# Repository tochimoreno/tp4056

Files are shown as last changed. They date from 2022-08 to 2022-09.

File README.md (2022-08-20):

# Batery charger with TP4056, protection and power path
forked from ...

Tomo el proyecto original como base para realizar uno nuevo que incluya un power path para mejor funcionamiento del cargador.

* Clean up and redraw the schematic
* Add power path
* Remove KiCad v5 files
* Add 3V3 LDO regulator
* Add divisor for measurment Bat voltage

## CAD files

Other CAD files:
tp4056_kicad6_base/tp4056.dxf

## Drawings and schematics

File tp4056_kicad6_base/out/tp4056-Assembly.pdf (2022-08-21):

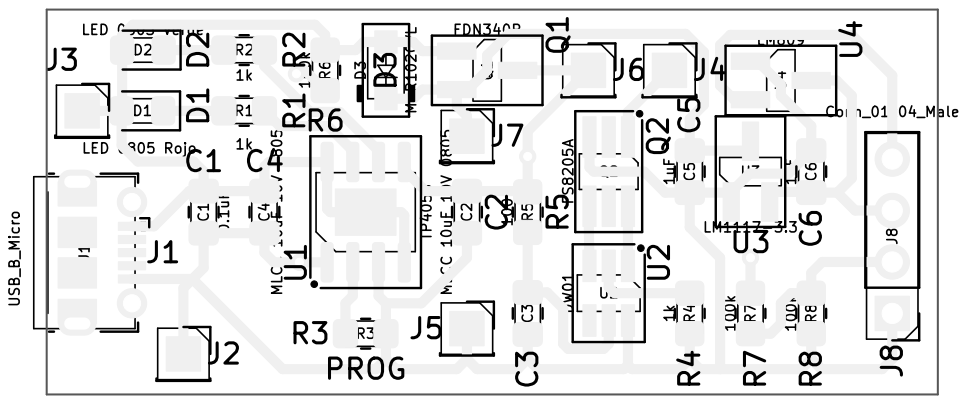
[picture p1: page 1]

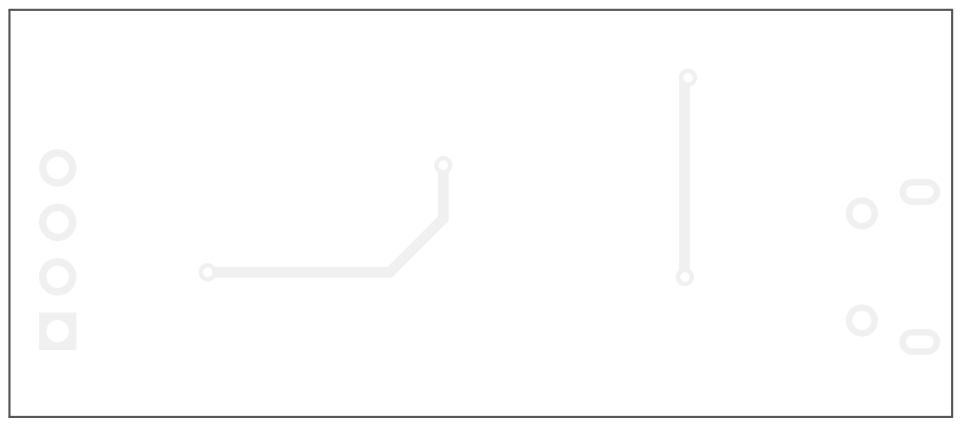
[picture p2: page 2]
D Date: KiCad E.D.A. kicad 6.0.7-f9a2dced07~116~ubuntu22.04.1 Size: A4; Rev:; Id: 1/1 Title:; File: tp4056.kicad_pcb; Sheet: Assembly

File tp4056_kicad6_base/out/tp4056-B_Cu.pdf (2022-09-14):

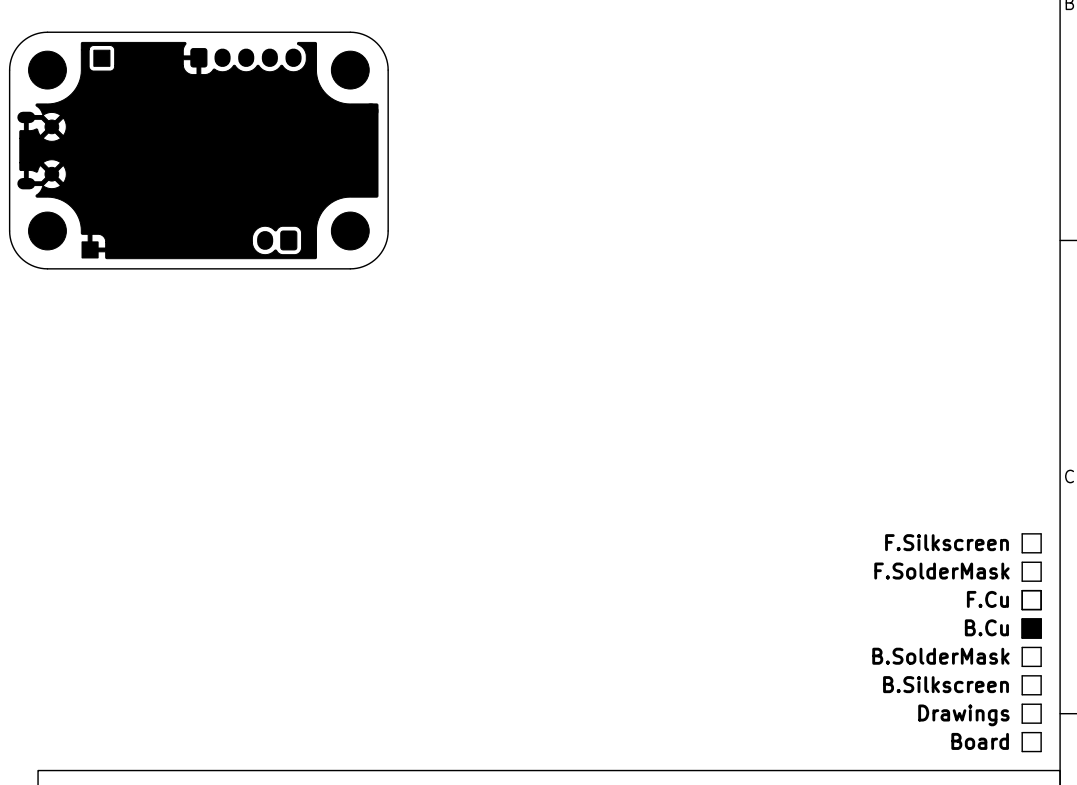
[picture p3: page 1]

F.SolderMask F.Silkscreen B.SolderMask F.Cu B.Cu B.Silkscreen Drawings

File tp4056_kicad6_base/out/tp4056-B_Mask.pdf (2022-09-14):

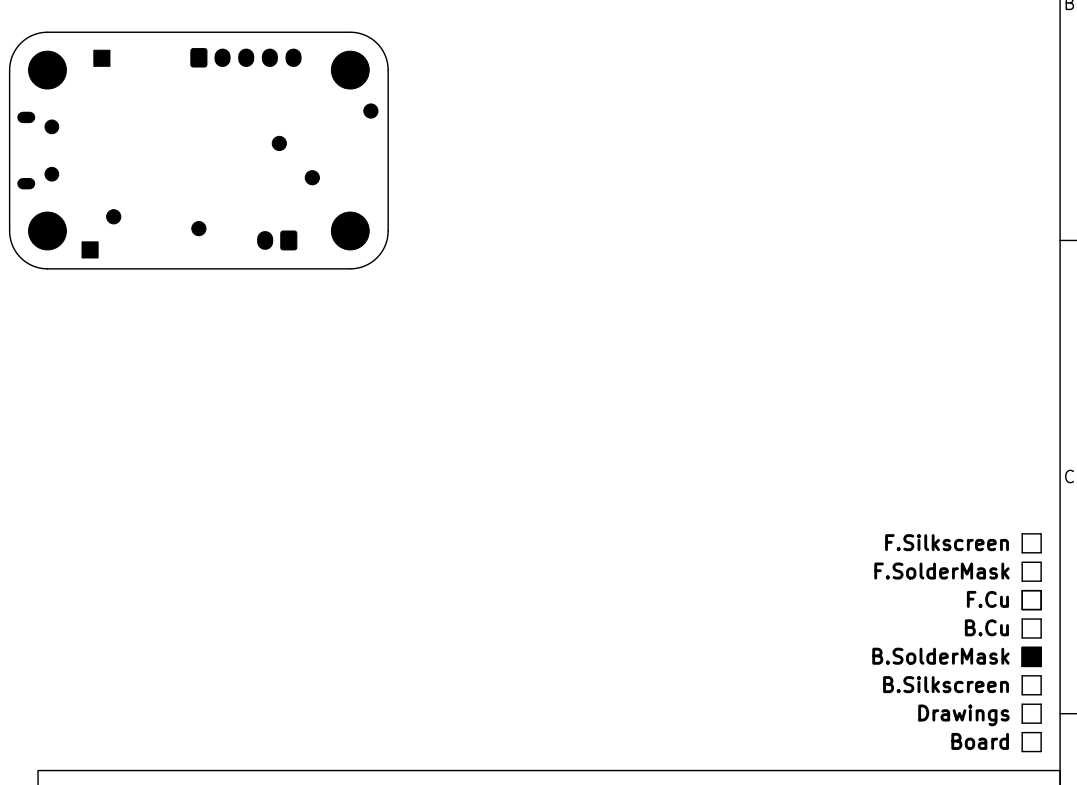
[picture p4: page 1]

F.SolderMask F.Silkscreen B.SolderMask F.Cu B.Cu B.Silkscreen Drawings

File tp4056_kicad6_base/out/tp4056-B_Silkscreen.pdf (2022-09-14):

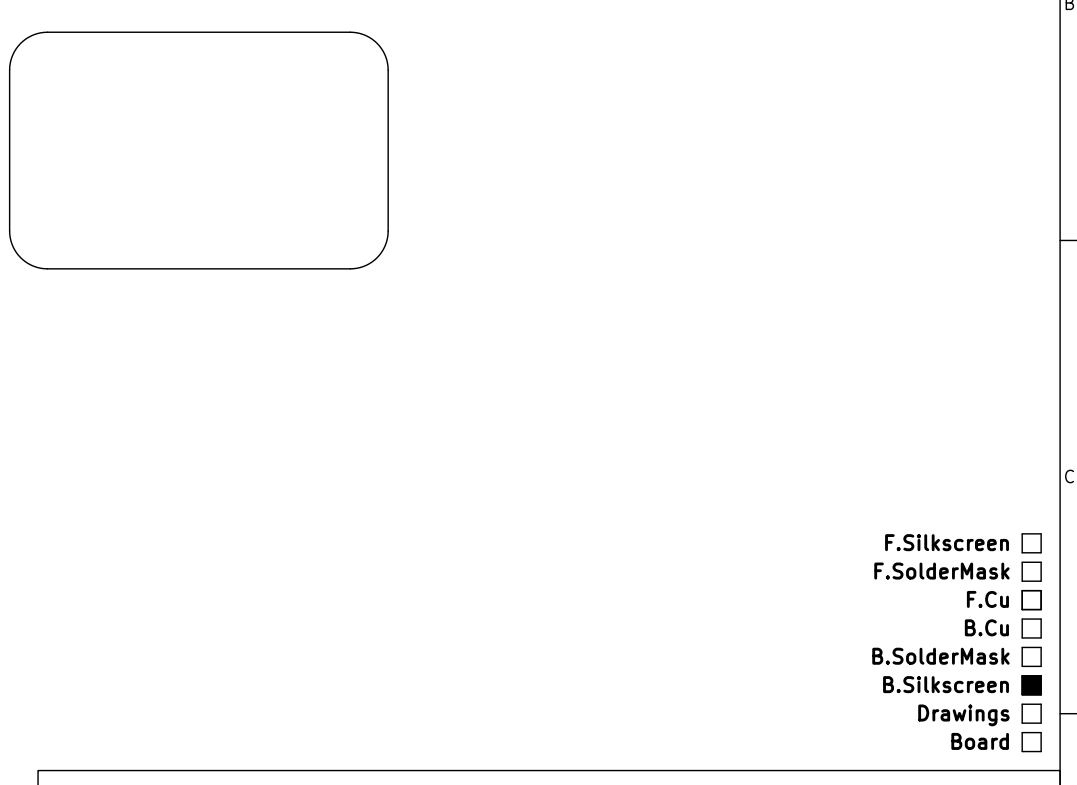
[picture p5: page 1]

F.SolderMask F.Silkscreen B.SolderMask F.Cu B.Cu B.Silkscreen Drawings

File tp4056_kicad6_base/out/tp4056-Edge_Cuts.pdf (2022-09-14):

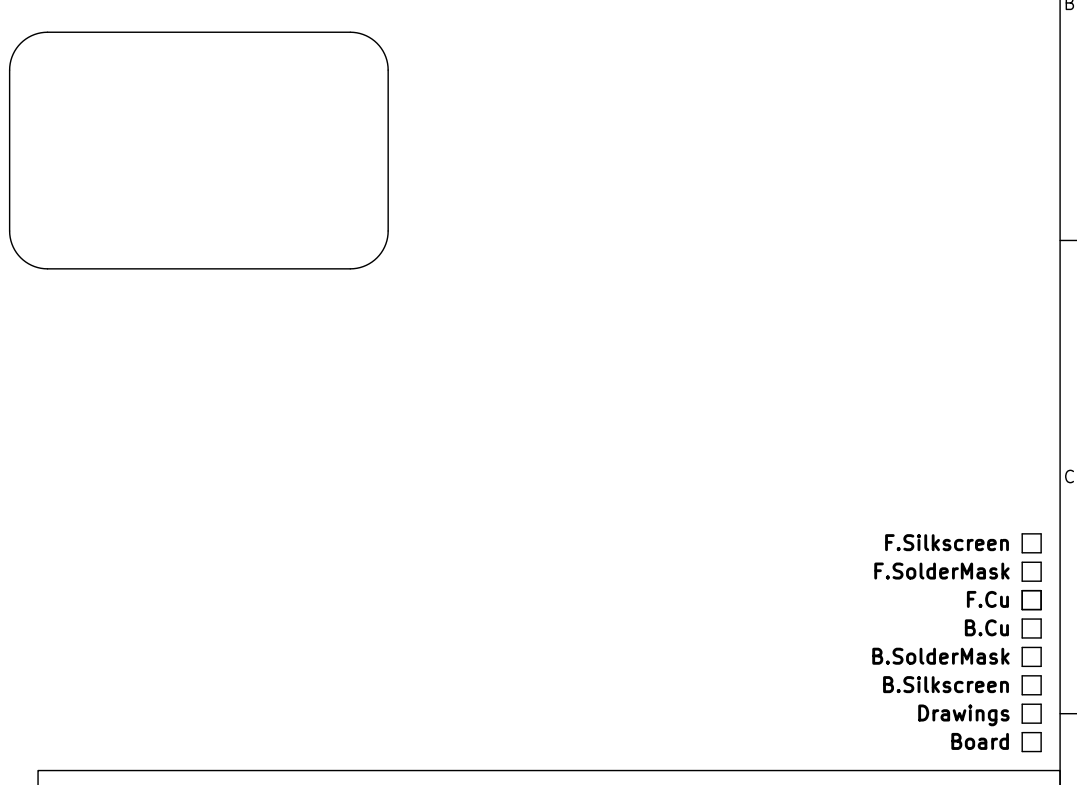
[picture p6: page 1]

F.SolderMask F.Silkscreen B.SolderMask F.Cu B.Cu B.Silkscreen Drawings

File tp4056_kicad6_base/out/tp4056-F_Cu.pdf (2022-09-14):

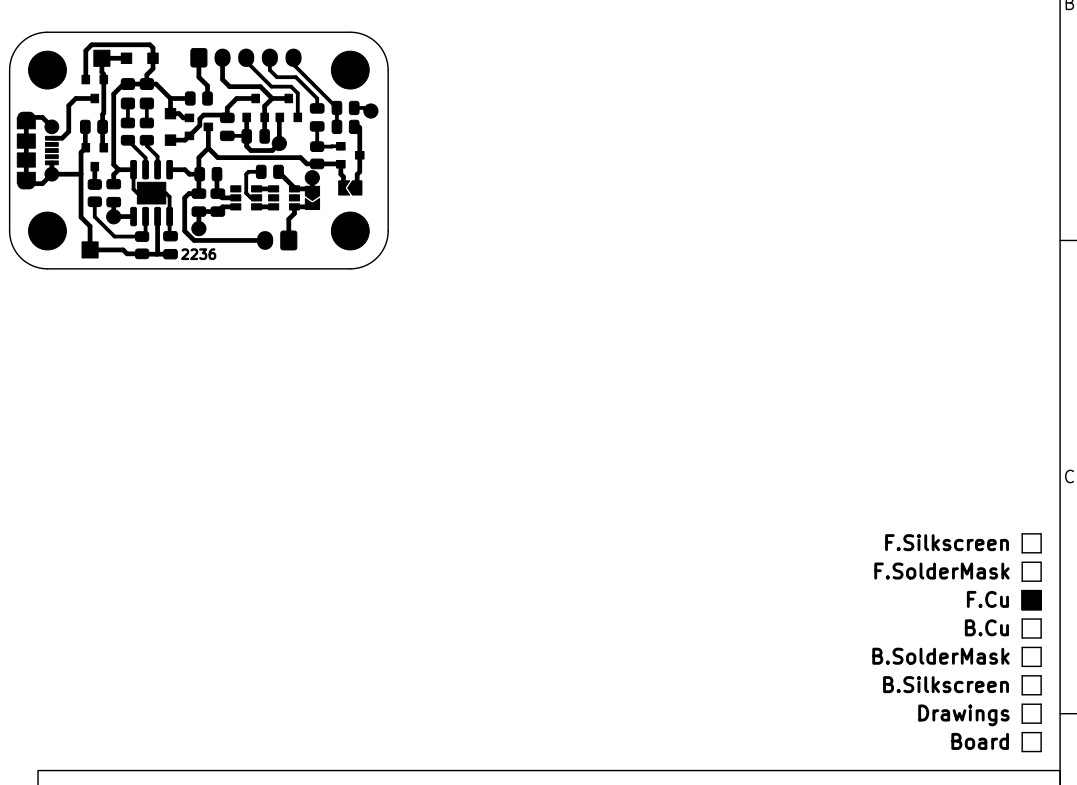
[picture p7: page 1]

F.SolderMask F.Silkscreen B.SolderMask F.Cu B.Cu B.Silkscreen Drawings

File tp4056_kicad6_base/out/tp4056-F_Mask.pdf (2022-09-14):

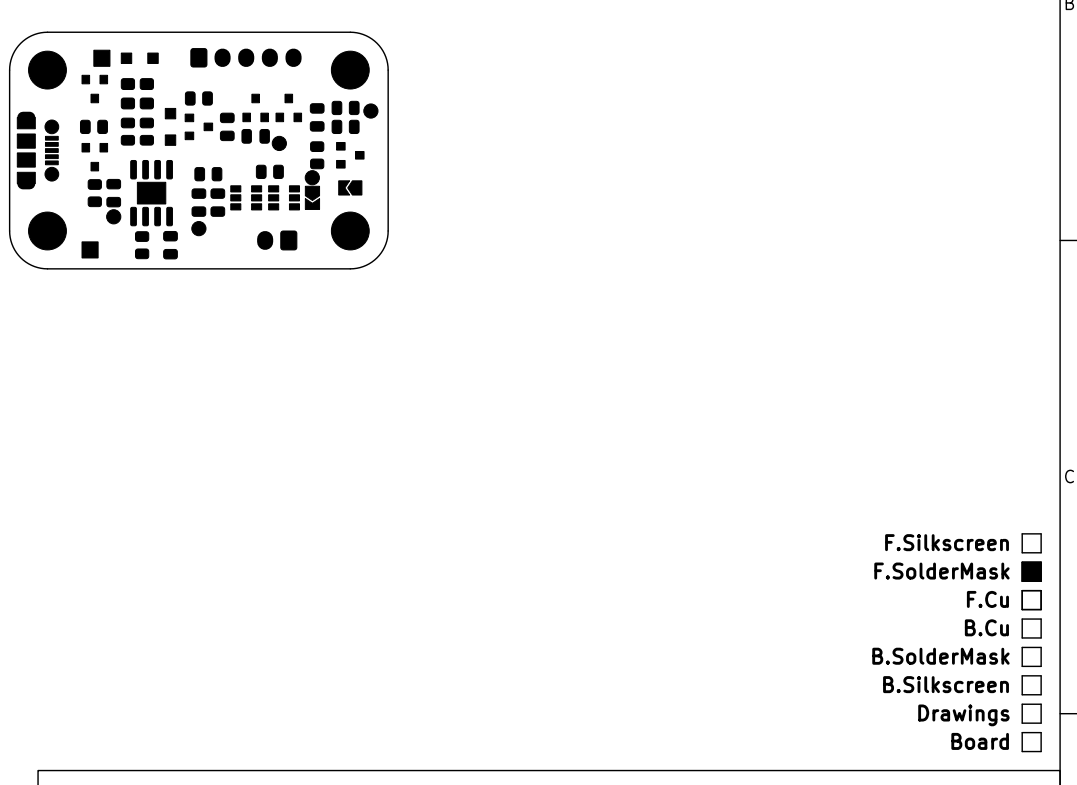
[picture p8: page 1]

F.SolderMask F.Silkscreen B.SolderMask F.Cu B.Cu B.Silkscreen Drawings

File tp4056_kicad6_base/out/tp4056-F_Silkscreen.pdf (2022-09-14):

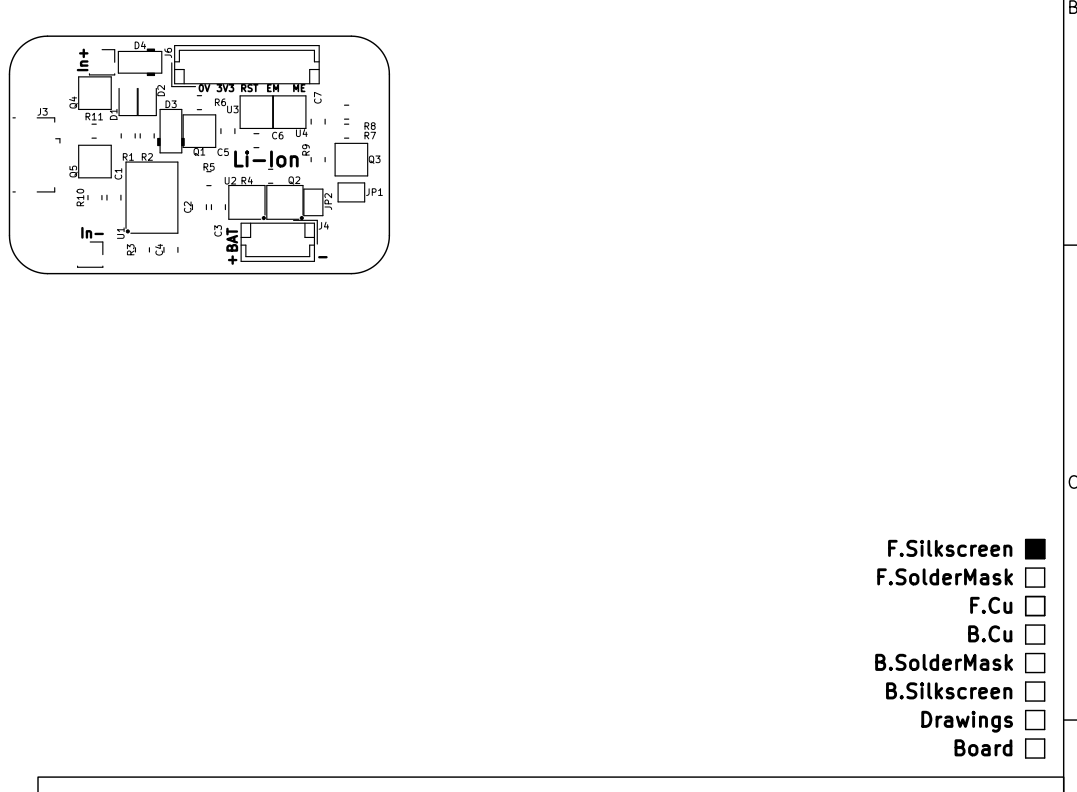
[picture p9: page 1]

0V 3V3 RST EM ME In+

F.SolderMask F.Silkscreen B.SolderMask F.Cu B.Cu B.Silkscreen Drawings

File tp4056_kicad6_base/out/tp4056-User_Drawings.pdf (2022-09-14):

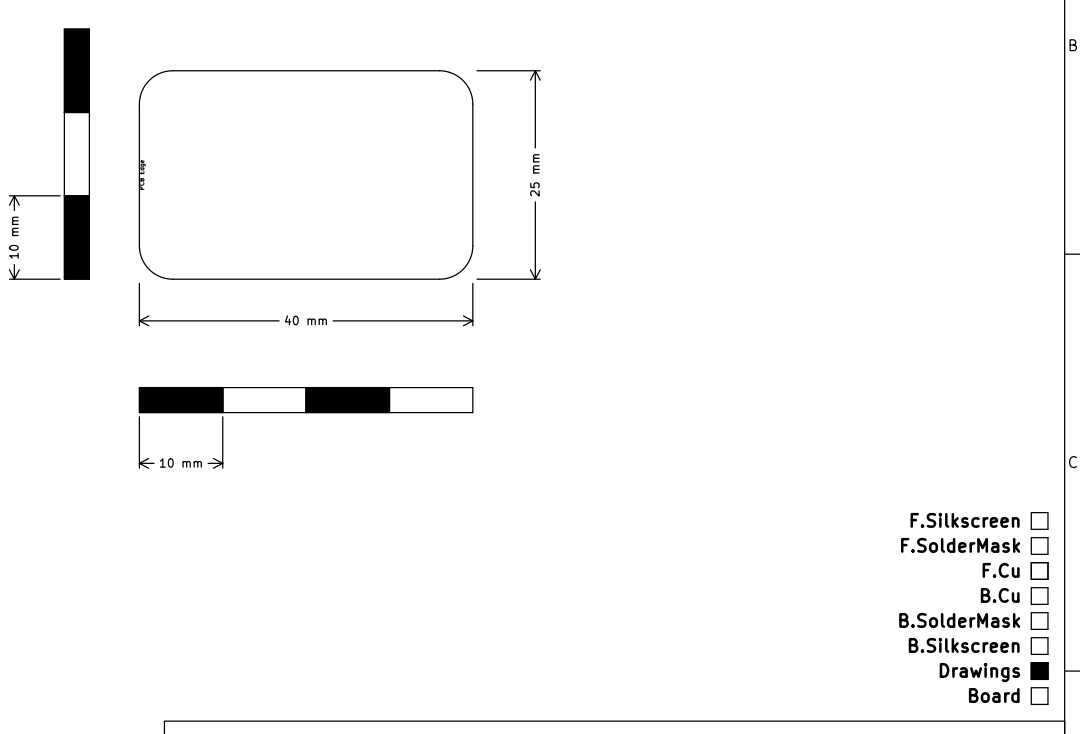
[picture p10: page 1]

F.SolderMask F.Silkscreen B.SolderMask F.Cu B.Cu B.Silkscreen Drawings 25 mm 10 mm

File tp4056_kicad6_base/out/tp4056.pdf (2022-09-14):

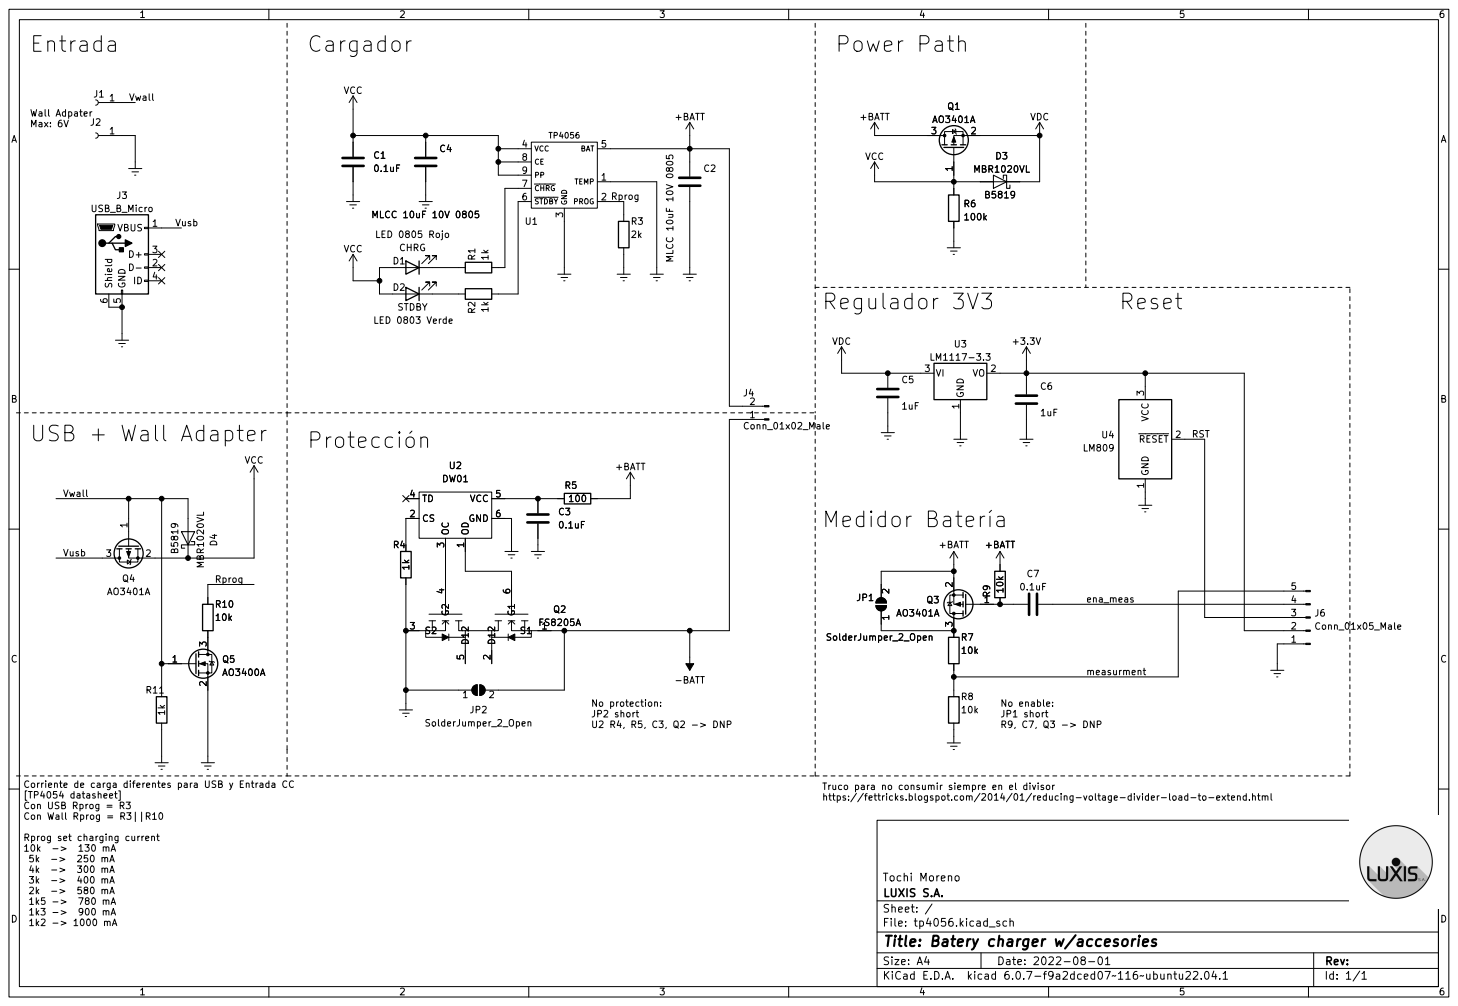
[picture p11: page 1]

3 TD 4 VCC 5 GND 6 U2 DW01 VBUS 1 D- 2 D+ 3

No enable: JP1 short R9, C7, Q3 -> DNP USB + Wall Adapter

No protection: JP2 short U2 R4, R5, C3, Q2 -> DNP

Corriente de carga diferentes para USB y Entrada CC
[TP4054 datasheet]
Con USB Rprog = R3
Con Wall Rprog = R3||R10

Truco para no consumir siempre en el divisor
https://fettricks.blogspot.com/2014/01/reducing-voltage-divider-load-to-extend.html

Rprog set charging current 10k -> 130 mA

Id: 1/1 Title: Batery charger w/accesories

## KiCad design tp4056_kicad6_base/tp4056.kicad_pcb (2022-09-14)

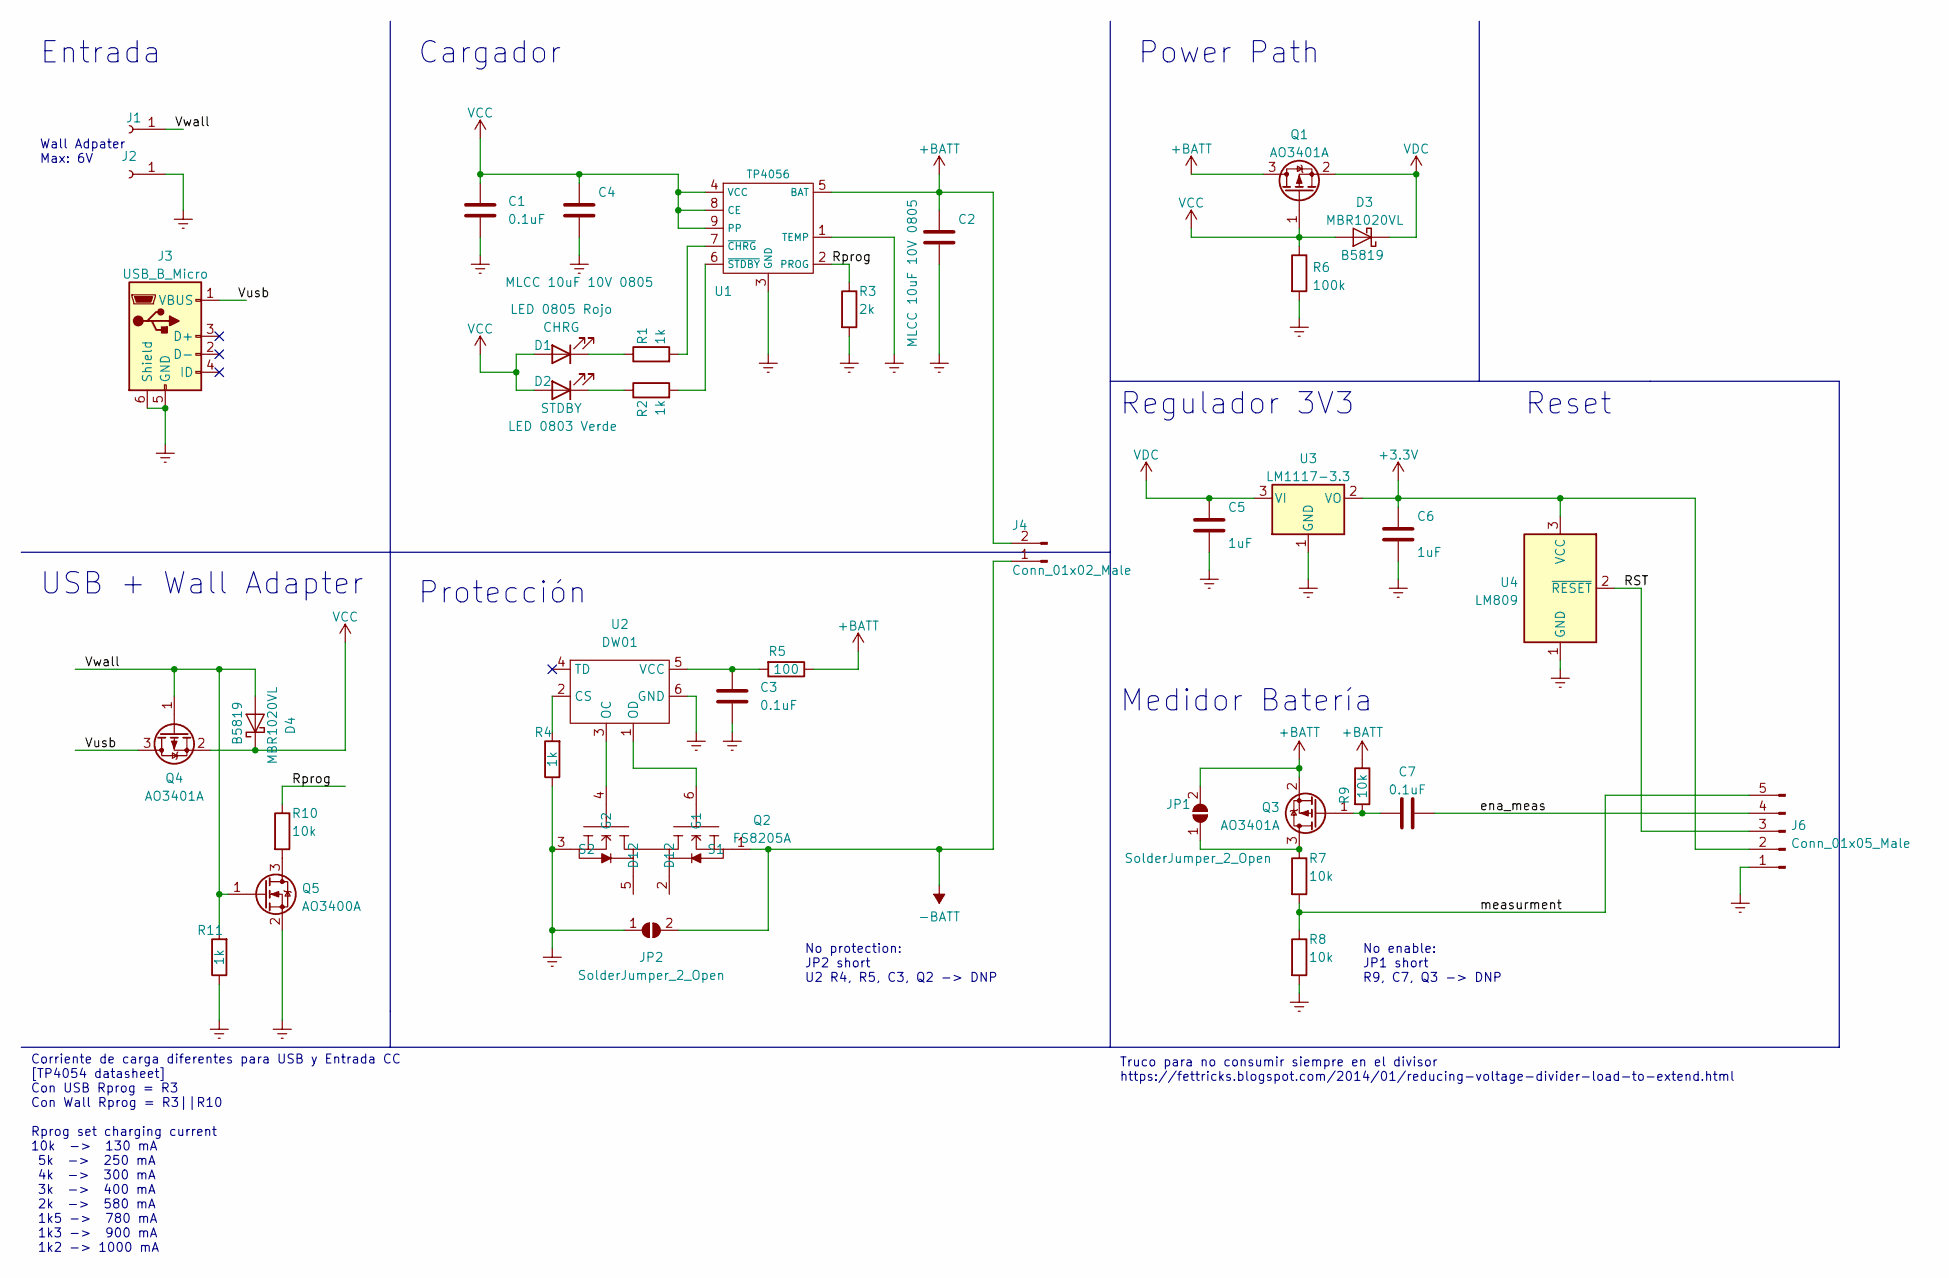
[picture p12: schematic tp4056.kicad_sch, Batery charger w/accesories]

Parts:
C1, C3, C7: 0.1uF; C_0805_2012Metric
C2, C4: MLCC 10uF 10V 0805; C_0805_2012Metric
C5, C6: 1uF; C_0805_2012Metric
D1: LED 0805 Rojo; LED_0805_2012Metric_Pad1.15x1.40mm_HandSolder
D2: LED 0803 Verde; LED_0805_2012Metric_Pad1.15x1.40mm_HandSolder
D3, D4: MBR1020VL; D_SOD-123F
J1, J2: Conn_01x01_Female; PinSocket_1x01_P2.54mm_Vertical
J3: USB_B_Micro; USB_Micro-B_Molex-105017-0001
J4: Conn_01x02_Male; JST_EH_B2B-EH-A_1x02_P2.50mm_Vertical
J6: Conn_01x05_Male; JST_EH_B5B-EH-A_1x05_P2.50mm_Vertical
JP1, JP2: SolderJumper_2_Open; SolderJumper-2_P1.3mm_Open_TrianglePad1.0x1.5mm
Q1, Q3, Q4: AO3401A; SOT-23
Q2: FS8205A; SOT-23-6
Q5: AO3400A; SOT-23
R1, R2, R4, R11: 1k; R_0805_2012Metric
R3: 2k; R_0805_2012Metric
R5: 100; R_0805_2012Metric
R6: 100k; R_0805_2012Metric
R7, R8, R9, R10: 10k; R_0805_2012Metric
U1: TP4056; SOIC-8-1EP_3.9x4.9mm_P1.27mm_EP2.29x3mm
U2: DW01; SOT-23-6
U3: LM1117-3.3; SOT-23
U4: LM809; SOT-23

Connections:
+3.3V: C6.1, J6.2, U3.2 (VO), U4.3 (VCC)
+BATT: C2.1, J4.2, JP1.2 (B), Q1.3 (D), Q3.2 (S), R5.1, R9.1, U1.5 (BAT)
-BATT: J4.1, JP2.2 (B), Q2.1 (S1)
/RST: J6.3, U4.2 (~RESET)
/Rprog: R3.1, R10.1, U1.2 (PROG)
/Vusb: J3.1 (VBUS), Q4.3 (D)
/Vwall: D4.2 (A), J1.1, Q4.1 (G), Q5.1 (G), R11.2
/ena_meas: C7.2, J6.4
/measurment: J6.5, R7.2, R8.1
Earth: C1.2, C2.2, C3.2, C4.2, C5.2, C6.2, J2.1, J3.5 (GND), J3.6 (Shield), J6.1, JP2.1 (A), Q2.3 (S2), Q5.2 (S), R3.2, R4.1, R6.2, R8.2, R11.1, U1.1 (TEMP), U1.3 (GND), U2.6 (GND), U3.1 (GND), U4.1 (GND)
unnamed: C3.1, R5.2, U2.5 (VCC)
unnamed: C7.1, Q3.1 (G), R9.2
unnamed: D1.1 (K), R1.1
unnamed: D2.1 (K), R2.1
unnamed: JP1.1 (A), Q3.3 (D), R7.1
unnamed: Q2.4 (G2), U2.3 (OC)
unnamed: Q2.6 (G1), U2.1 (OD)
unnamed: Q5.3 (D), R10.2
unnamed: R1.2, U1.7 (~CHRG)
unnamed: R2.2, U1.6 (~STDBY)
unnamed: R4.2, U2.2 (CS)
VDC: C5.1, D3.1 (K), Q1.2 (S), U3.3 (VI)

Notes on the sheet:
Power Path
Corriente de carga diferentes para USB y Entrada CC [TP4054 datasheet] Con USB Rprog = R3 Con Wall Rprog = R3||R10 Rprog set charging current 10k -> 130 mA 5k -> 250 mA 4k -> 300 mA 3k -> 400 mA 2k -> 580 mA 1k5 -> 780 mA 1k3 -> 900 mA 1k2 -> 1000 mA
No protection: JP2 short U2 R4, R5, C3, Q2 -> DNP
Medidor Batería
USB + Wall Adapter
Reset
Truco para no consumir siempre en el divisor https://fettricks.blogspot.com/2014/01/reducing-voltage-divider-load-to-extend.html
Cargador
Protección
Entrada
Wall Adpater Max: 6V
No enable: JP1 short R9, C7, Q3 -> DNP
Regulador 3V3

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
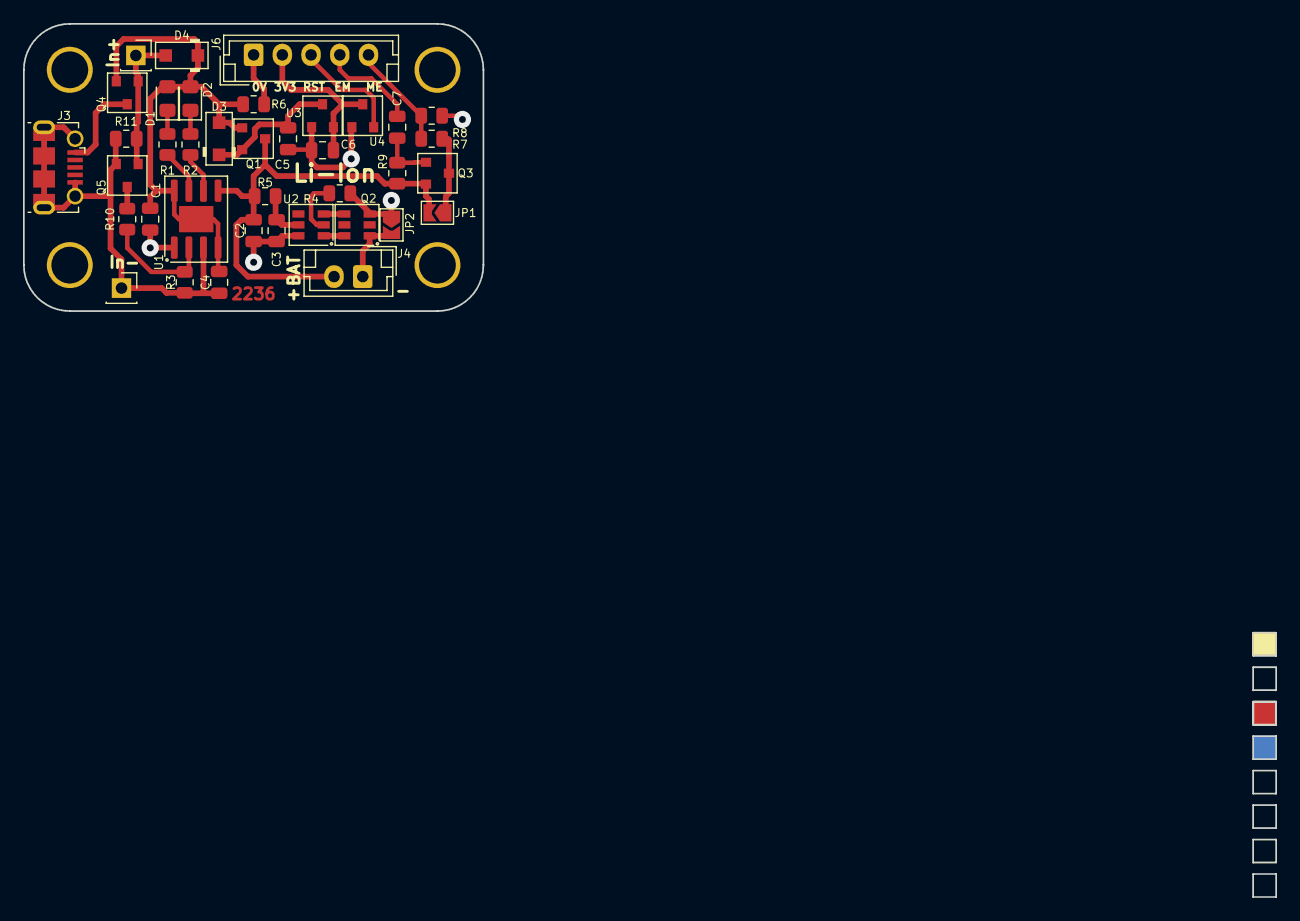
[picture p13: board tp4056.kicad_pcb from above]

Board: 2 copper layers, 40.0 x 25.0 mm, 38 parts (0 on the bottom side), 23 nets.

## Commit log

2022-08-01 redraw and add power path
    [tp4056.kicad_sch]
2022-08-01 fix output path
    [tp4056.kicad_sch]
2022-08-02 remove KiCad v5 files
    [charger_stepup.kicad_pcb, charger_stepup.sch]
2022-08-02 add Rprog table
    [tp4056.csv, tp4056.kicad_sch]
2022-08-19 add 3v3 regulator
    [tp4056.kicad_pcb, tp4056.kicad_sch]
2022-08-20 Add 3.3V LDO regulator
    [tp4056.kicad_pcb, tp4056.kicad_sch]
2022-08-20 Cambios estéticos en el sch
    [tp4056.kicad_sch]
2022-08-20 pcd.Add board and position elements
    [tp4056.kicad_pcb, tp4056.kicad_sch]
2022-08-20 pcb. Board ready in 4032
    [tp4056.kicad_pcb]
2022-08-20 pcb. Board 38x18
    [tp4056.kicad_pcb, tp4056.kicad_sch]
2022-08-21 sch. add voltage supervisor.
    [tp4056.kicad_sch]
2022-08-21 pcb. board 40x20 one layer
    [tp4056.kicad_pcb, tp4056.kicad_sch]
2022-08-21 finish version 44x19mm
    [tp4056.dxf, tp4056.kicad_pcb]
2022-08-22 pcb. new version 29x23. OJO Revisar disponibilidad de MOSFET!
    [tp4056.kicad_pcb, tp4056.kicad_sch, tp4056_44x19.kicad_pcb]
2022-08-23 sch. redraw and organization
    [tp4056.kicad_sch]
2022-08-30 Add zero-power measurment. Some connectors change.
    [tp4056.kicad_sch]
2022-09-04 Change conectors. Add jumpers. PCB ready 48x20.
    [tp4056.kicad_pcb, tp4056.kicad_sch]
2022-09-04 PCB update
    [tp4056.kicad_pcb]
2022-09-05 PCB 40x32
    [tp4056.kicad_pcb]
2022-09-07 PCB 40x25. To check DRC
    [tp4056-B_Cu.gbr, tp4056-B_Mask.gbr, tp4056-F_Cu.gbr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]
2022-09-13 SCH. Add USB and Wall Power Adaptor
    [tp4056.kicad_pcb, tp4056.kicad_sch]
2022-09-14 PCB. 40x25. Add wall adpapter option. To final check.
    [tp4056.kicad_pcb, tp4056.kicad_sch]
2022-09-14 PCB. output files. minor cosmetic changes.
    [tp4056-B_Mask.gbr, tp4056-B_Silkscreen.gbr, tp4056-Edge_Cuts.gbr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]
